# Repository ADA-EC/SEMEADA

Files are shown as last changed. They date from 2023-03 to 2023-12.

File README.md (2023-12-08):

# 🤖 SEMEADA

## O que é o projeto?
O projeto, desenvolvido pela [ADA](http://adaec.icmc.usp.br/sobre-nos/) em parceria com o [SEMEAR](https://semear.eesc.usp.br/), se trata de um robô de mesa capaz de captar comandos de fala e interpretá-los, por meio de **processamento de linguagem natural**, para realizar ações. Até o momento, o robô é capaz de obedecer aos seguintes comandos:
* Dançar
* Acordar
* Dormir
* Girar
* Levantar os braços
* Contar uma piada
* Falar sobre seu atual estado emocional
* Se apresentar
* Falar sobre a ADA
* Falar sobre o SEMEAR
* Tocar uma música
* Soletrar uma palavra
* Falar sobre o projeto

Além disso, o robô, através de máquinas de estado, possui a habilida de **simular sentimentos**, tendo assim um **"estado de espírito"**.

A seguir descrevemos mais detalhadamente o funcionamento do projeto.

## Funcionamento
Quando o robô é inicializado, o mesmo fica em estado de espera, aguardando o acionamento. Quando recebe a mensagem "Ouvir", inicia a captação de áudio (posteriormente será utilizado um botão para iniciar a captação). O áudio é armazenado em uma faixa de som (audio.wav) posteriormente enviada para `processamento_voz.py`, que utiliza a biblioteca `speech_recognition` para transformar o áudio captado em texto. O texto então é submetido 

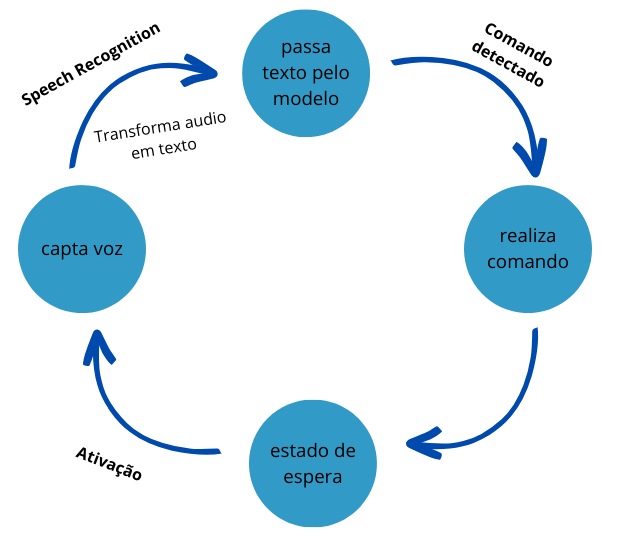
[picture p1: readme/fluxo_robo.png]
Fluxo


## Executando o projeto
### Treinando o modelo
Para treinar o modelo utilizar as instruções contidas [nesse guia](https://github.com/ADA-EC/SEMEADA/tree/main/Treinamento_PLN)

### Rodando o código
Para rodar o projeto, executar o comando: <br>
`python Esqueleto/main.py`

## Estrutura de pastas do projeto
- 📁 Codigo ➡️ contém arquivos de estudo do início do projeto
- 📁 Esqueleto ➡️ contém todo o código do robô
  - 🐍`comandos.py` ➡️ mapemaneto dos comandos em números, chamado pelo PLN
  - 🐍`commSerial.py` ➡️ faz a comunicação do código python com o Arduino, chamada pela máquina de estados
  - 🐍`main.py` ➡️ coordena todas as funções do robô
    - inicializa o robô
    - chama o processamento de áudio
    - recebe o texto de volta
    - envia o texto para o processamento
    - recebe o número do comando
    - envia para a máquina de estados   
  - 🐍`olhos.py` ➡️ mapeamento dos olhos para cada estado de humor
  - 🐍`PLN.py` ➡️ recebe o texto da *main*, faz o pré processamento do texto, submete ao modelo, retorna o valor do comando para a *main*
  - 🐍`processamento_voz.py` ➡️ chamada pela *main*, capta o áudio, transforma em texto e retorna para a *main*
  - 🐍`rostos.py` ➡️ faz a conexão com o arduino (não sei se está sendo utilizada, verificar remoção)
  - 🐍`sintese_voz.py` ➡️ usado para repetir o comando de voz de volta (verificar remoção)
  - 🐍`state_machine.py` ➡️ controla o estado de humor do robô, gerencia execução dos comandos (recebe da *main* o comando e envia para *commSerial*)
- 📁 Falhas_treinamento_PLN ➡️ contém o histórico de tentativas de treinamento do modelo
- 📁 Gravar ➡️ armazena o arquivo de áudio captado
- 📁 Maquina_Estados ➡️ contém as imagens das máquinas de estados desenvolvidas no JFLAP
- 📁 Olhos ➡️ contém os arquivos com as imagens usada para teste das telas LCD
- 📁 PCB ➡️ contém o projeto das placas do robô
- 📁 Testes Arduino ➡️ contém os arquivos comunicação com os componentes físicos do robô
- 📁 Treinamento_PLN ➡️ contém os arquivos de treinamento do modelo de processamento de linguagem natural

## O hardware

## Tecnologias Usadas

### Bibliotecas utilizadas
A seguir uma lista das bibliotecas utilizadas e como fazer sua instalação, além de dicas para contornar possíveis erros durante a instalação. (Todas as instalações foram feitas utilizando o pip, não usar o WSL)
- Pandas <br>
  `pip install pandas`
- SpaCy <br>
  `pip install spacy`
- Seaborn <br>
  `pip install seaborn`
- SpaCy Language Detector <br>
  `pip install spacy-langdetect`
- SpaCy pt_core_news_sm <br>
  `python -m spacy download pt_core_news_sm`
- gTTS <br>
  `pip install gTTS`
- SpeechRecognition [Caso não dê certo, tente rodar “pip3 install SpeechRecognition”] <br>
  `pip install SpeechRecognition`
- PlaySound [Caso não dê certo, tente dar um downgrade para a versão 1.2.2 (pip install playsound==1.2.2)] <br>
  `pip install playsound==1.2.2`
- PyDub <br>
  `pip install pydub`
- SoundDevice <br>
  `pip install sounddevice`
- SoundFile <br>
  `pip install SoundFile`
- Pyserial <br>
  `pip install pyserial`
- PyAudio <br>
  `pip install pyaudio`

### Máquina de Estados
Para realizar o projeto, fizemos algumas máquinas de estados modificadas que indicam o estado do robô após realizar os comandos.
Um exemplo disso é a maquina de estado desenvolvida para vários comandos diversos, mostrada abaixo. Nela, após realizar um comando como dançar, ele fica automaticamente no estado de "feliz".

Máquina de Estados - Diversos

Além disso, nota-se na imagem que alguns comandos não serão obedecidos se o robô estiver em determinado estado emocional, como o comando "dançar" também, que só pode ser realizado quando este está "feliz", "neutro" ou "triste".

Alguns comentários foram adicionados aos desenhos, para facilitar compreensão e auxiliar no entendimento na hora de construir o código em Python. Um exemplo de comentário pode ser visto na imagem abaixo, referente à máquina de estados "Tocar música".

Máquina de Estados - Tocar Música

## Membros
- [Érika Hortência](https://github.com/erika-hortencia)
- [Gabriela Barion Vidal](https://github.com/GabrielaVidal7)
- [Rodrigo Bragato Piva](https://github.com/Rodrigo-P)
- Marcos Almeida

## Agradecimentos
- [Victor Amaral](https://github.com/felfipe)
- [Breno Seixas]([https://github.com/TsuyoshiSonobe](https://github.com/TheGuardianB))
- [Tsuyoshi Sonobe](https://github.com/TsuyoshiSonobe)
- [Pedro Torrente](https://github.com/pdrtorrente)
- Manuella Porto

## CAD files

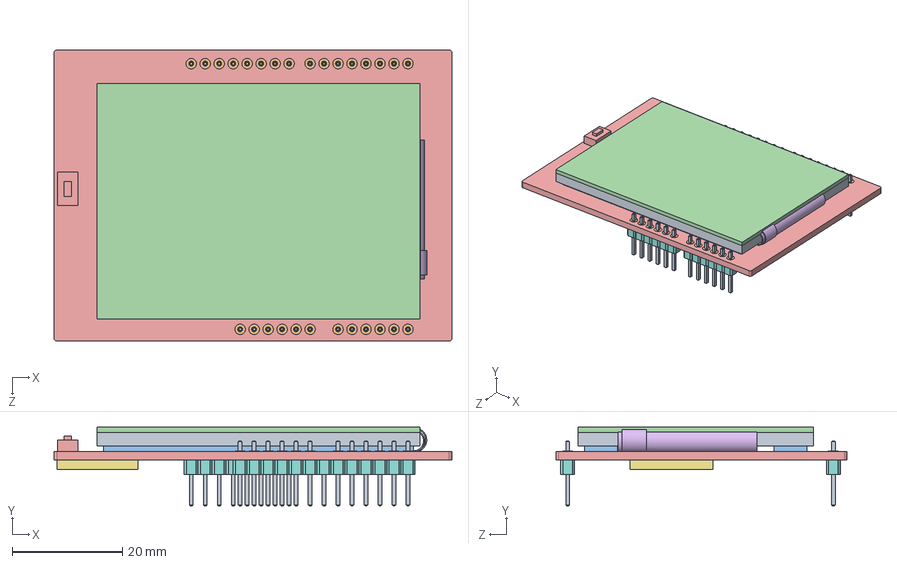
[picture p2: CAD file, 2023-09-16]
PCB/Componentes/2.4_INCH_TFT_DISPLAY_SHIELD_WITH_HEADER (1).STEP
72.3 x 14.3 x 52.9 mm
2.4INCH_TFT_DISPLAY_SHIELD_FOR_ARDUINO
PIN_HEADER_MALE_2.54MM_PITCH_6 WAY x 2
PIN_HEADER_MALE_2.54MM_PITCH_8 WAY x 2

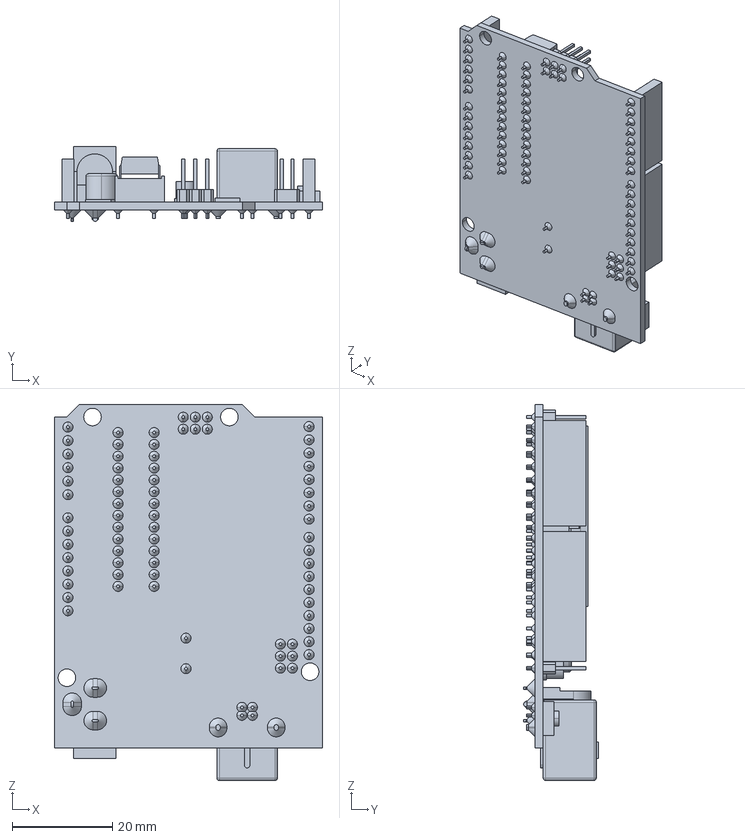
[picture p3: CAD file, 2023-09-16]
PCB/Componentes/arduino/Arduino-UNO.stp
53.5 x 14.9 x 75.0 mm

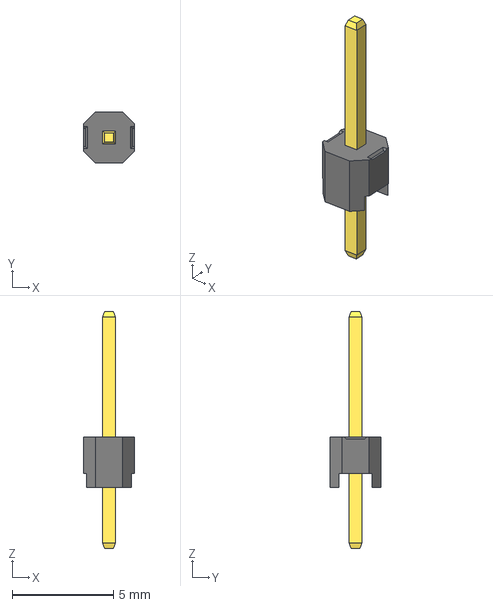
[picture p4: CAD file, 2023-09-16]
PCB/Componentes/Pin connector/PLS-1_(DS1021_CONNFLY).stp
2.54 x 2.54 x 11.7 mm

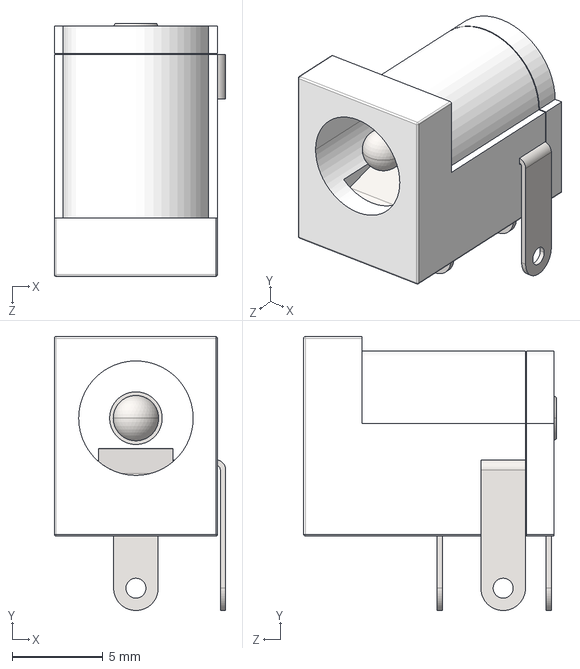
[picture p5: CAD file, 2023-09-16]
PCB/Componentes/JACK P4 PCI 2,5mm.STEP
9.45 x 15.1 x 13.9 mm

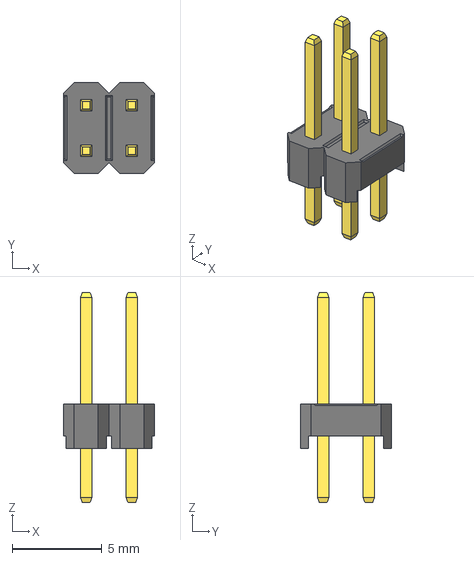
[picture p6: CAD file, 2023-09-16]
PCB/Componentes/Pin connector/PLD-4_(DS1021_CONNFLY).stp
5.08 x 5.08 x 11.7 mm

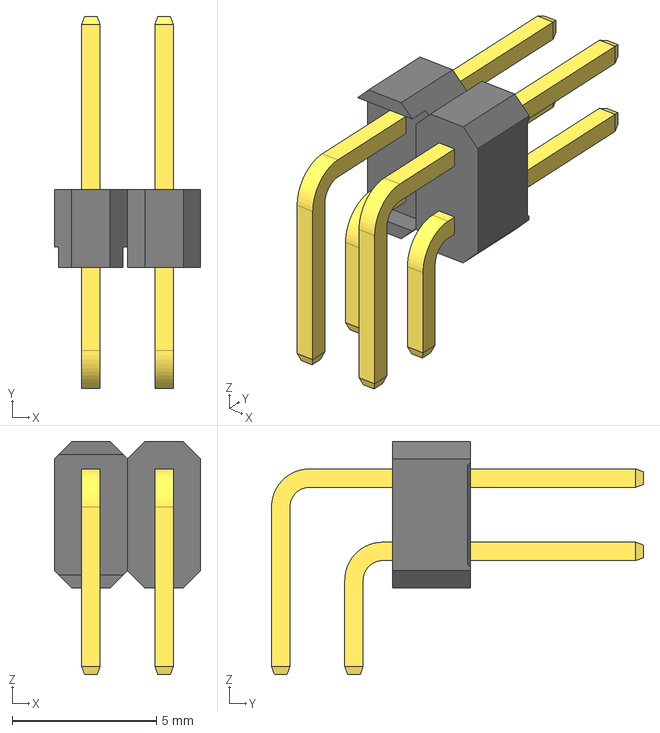
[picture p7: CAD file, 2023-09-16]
PCB/Componentes/Pin connector/PLD-4RD_(DS1022_CONNFLY).stp
5.08 x 12.9 x 8.08 mm

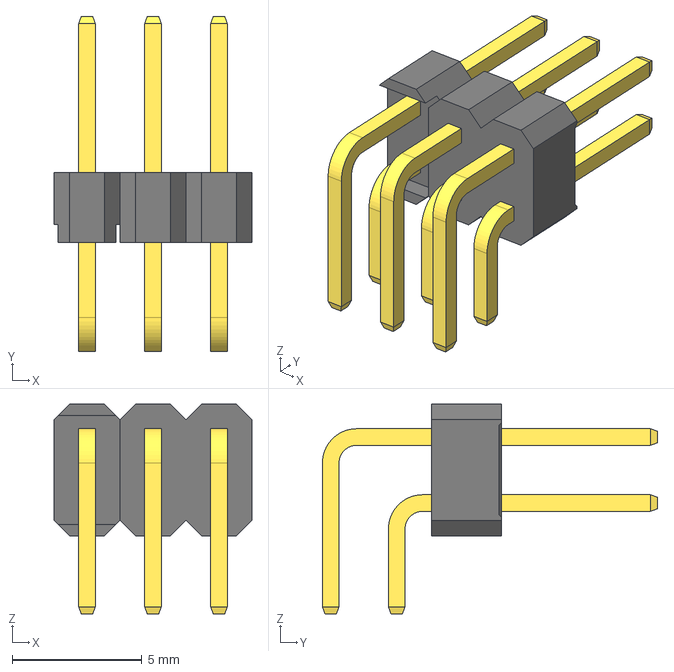
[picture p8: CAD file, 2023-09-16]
PCB/Componentes/Pin connector/PLD-6RD_(DS1022_CONNFLY).stp
7.62 x 12.9 x 8.08 mm

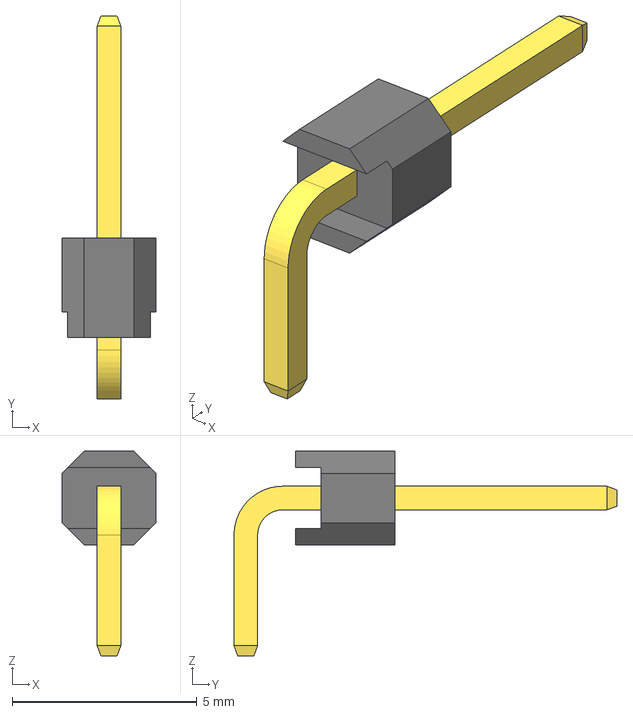
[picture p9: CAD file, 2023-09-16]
PCB/Componentes/Pin connector/PLS-1RD_(DS1022_CONNFLY).stp
2.54 x 10.4 x 5.54 mm

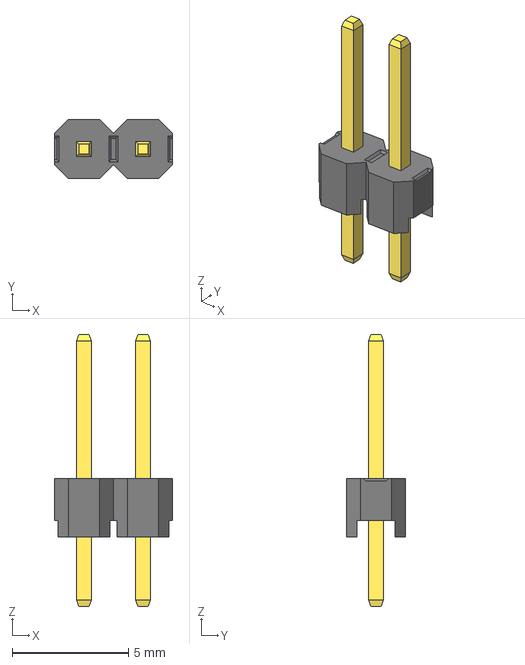
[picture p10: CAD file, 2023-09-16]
PCB/Componentes/Pin connector/PLS-2_(DS1021_CONNFLY).stp
5.08 x 2.54 x 11.7 mm

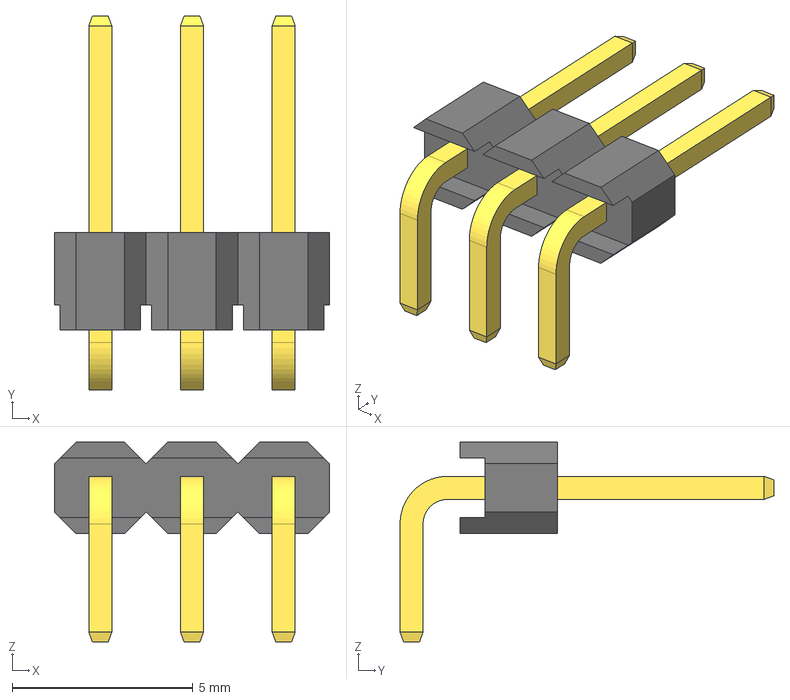
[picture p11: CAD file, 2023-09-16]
PCB/Componentes/Pin connector/PLS-3RD_(DS1022_CONNFLY).stp
7.62 x 10.4 x 5.54 mm

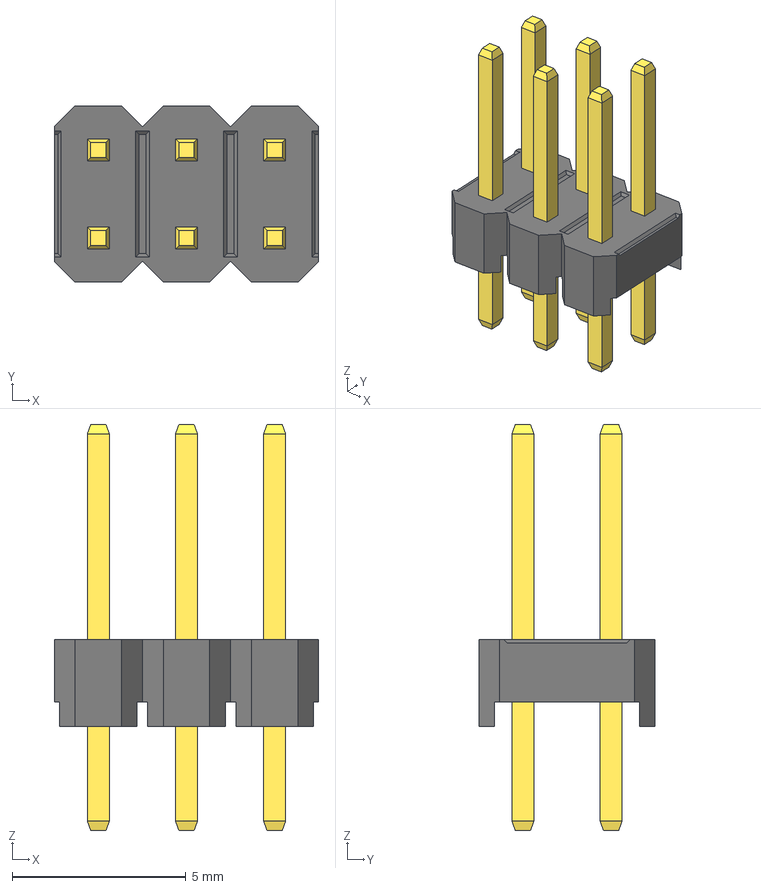
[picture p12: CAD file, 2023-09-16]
PCB/Componentes/Pin connector/PLD-6_(DS1021_CONNFLY).stp
7.62 x 5.08 x 11.7 mm

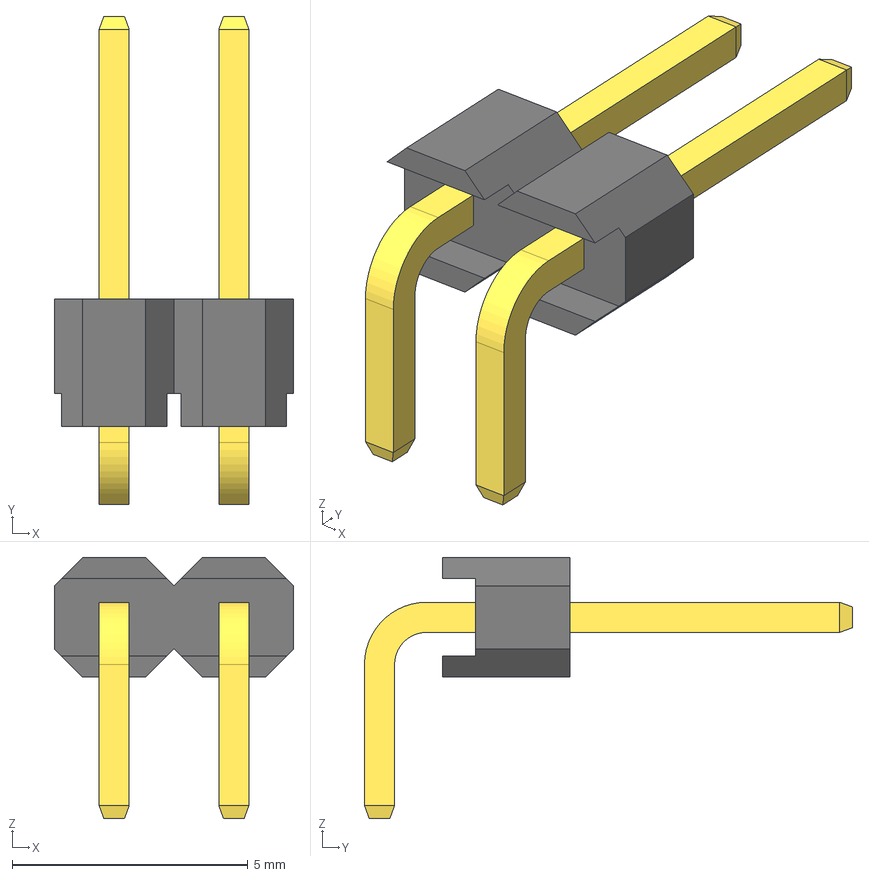
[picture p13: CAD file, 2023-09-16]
PCB/Componentes/Pin connector/PLS-2RD_(DS1022_CONNFLY).stp
5.08 x 10.4 x 5.54 mm

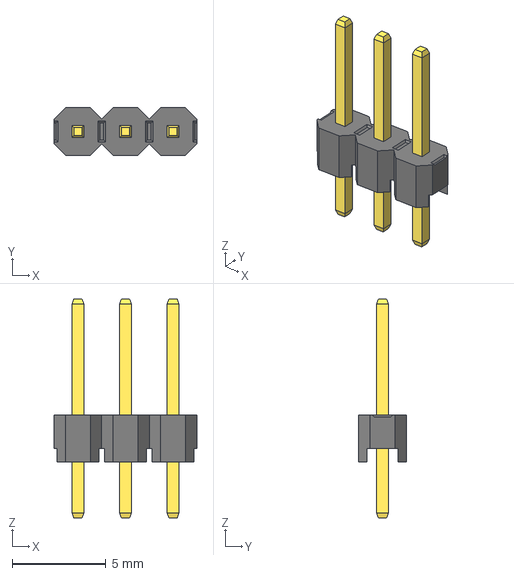
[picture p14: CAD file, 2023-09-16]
PCB/Componentes/Pin connector/PLS-3_(DS1021_CONNFLY).stp
7.62 x 2.54 x 11.7 mm

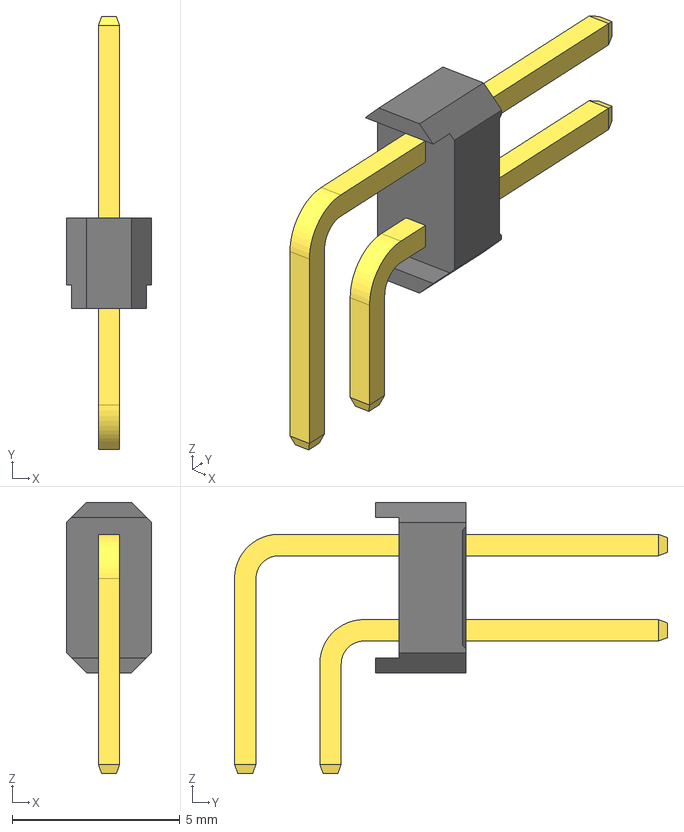
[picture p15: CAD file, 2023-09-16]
PCB/Componentes/Pin connector/PLD-2RD_(DS1022_CONNFLY).stp
2.54 x 12.9 x 8.08 mm

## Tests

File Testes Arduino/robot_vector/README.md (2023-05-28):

# Robot Eyes

Código que lê o bitmap dos olhos com diferentes emoções e mostra na tela. Resolvemos utilizar o bitmap ao invés de carregar uma imagem dos olhos na tela porque estavamos tendo problemas com o acesso da tela ao cartão microSD que ele possui.

O bitmap dos olhos está localizado no arquivo 'eyes.h'.

As animações dos olhos existentes são:
- Olho aberto
- Olho fechado
- Bravo
- Triste
- Feliz

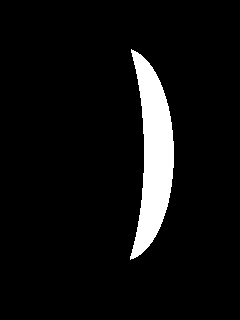
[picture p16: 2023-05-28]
Testes Arduino/TesteComunicacaoTelaSimples/feliz.bmp

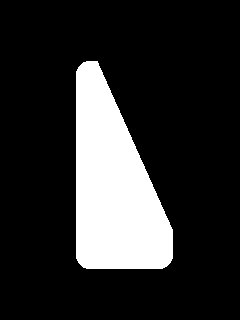
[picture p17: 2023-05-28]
Testes Arduino/TesteComunicacaoTela/triste_esq.bmp

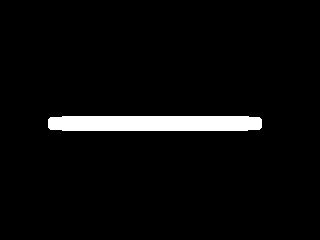
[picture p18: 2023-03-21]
Testes Arduino/robot_vector/pisca.bmp

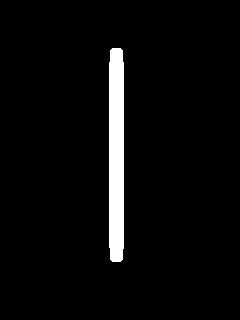
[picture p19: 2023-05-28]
Testes Arduino/TesteComunicacaoTelaSimples/pisca.bmp

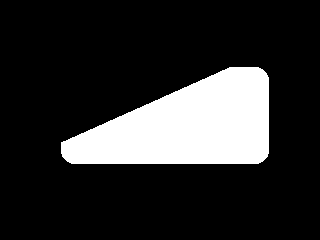
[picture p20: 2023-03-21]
Testes Arduino/robot_vector/triste_esq.bmp

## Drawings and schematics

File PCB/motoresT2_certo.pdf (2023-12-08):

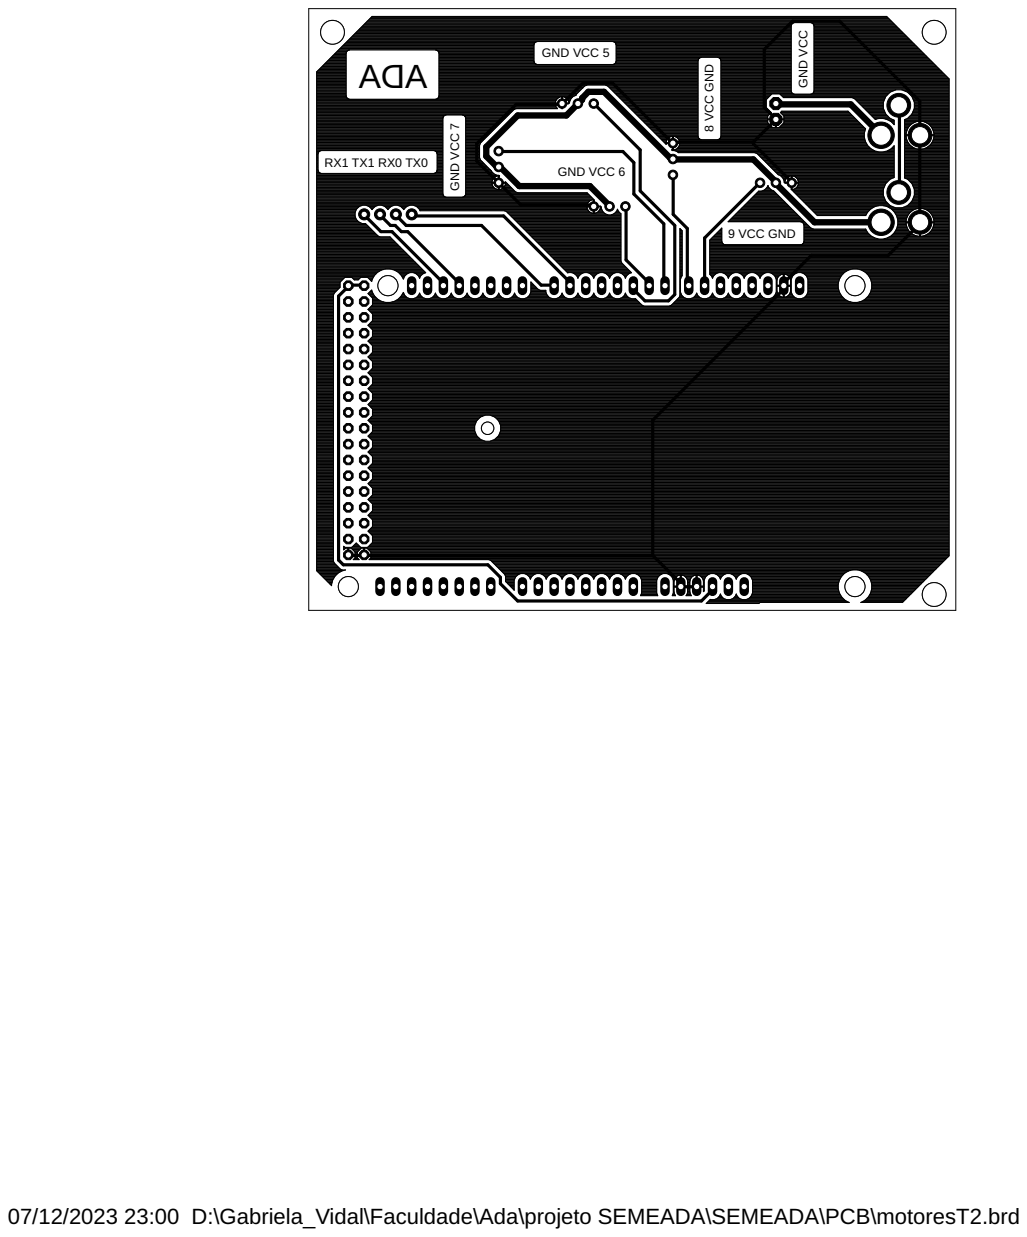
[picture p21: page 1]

07/12/2023 23:00 D:\Gabriela_Vidal\Faculdade\Ada\projeto SEMEADA\SEMEADA\PCB\motoresT2.brd

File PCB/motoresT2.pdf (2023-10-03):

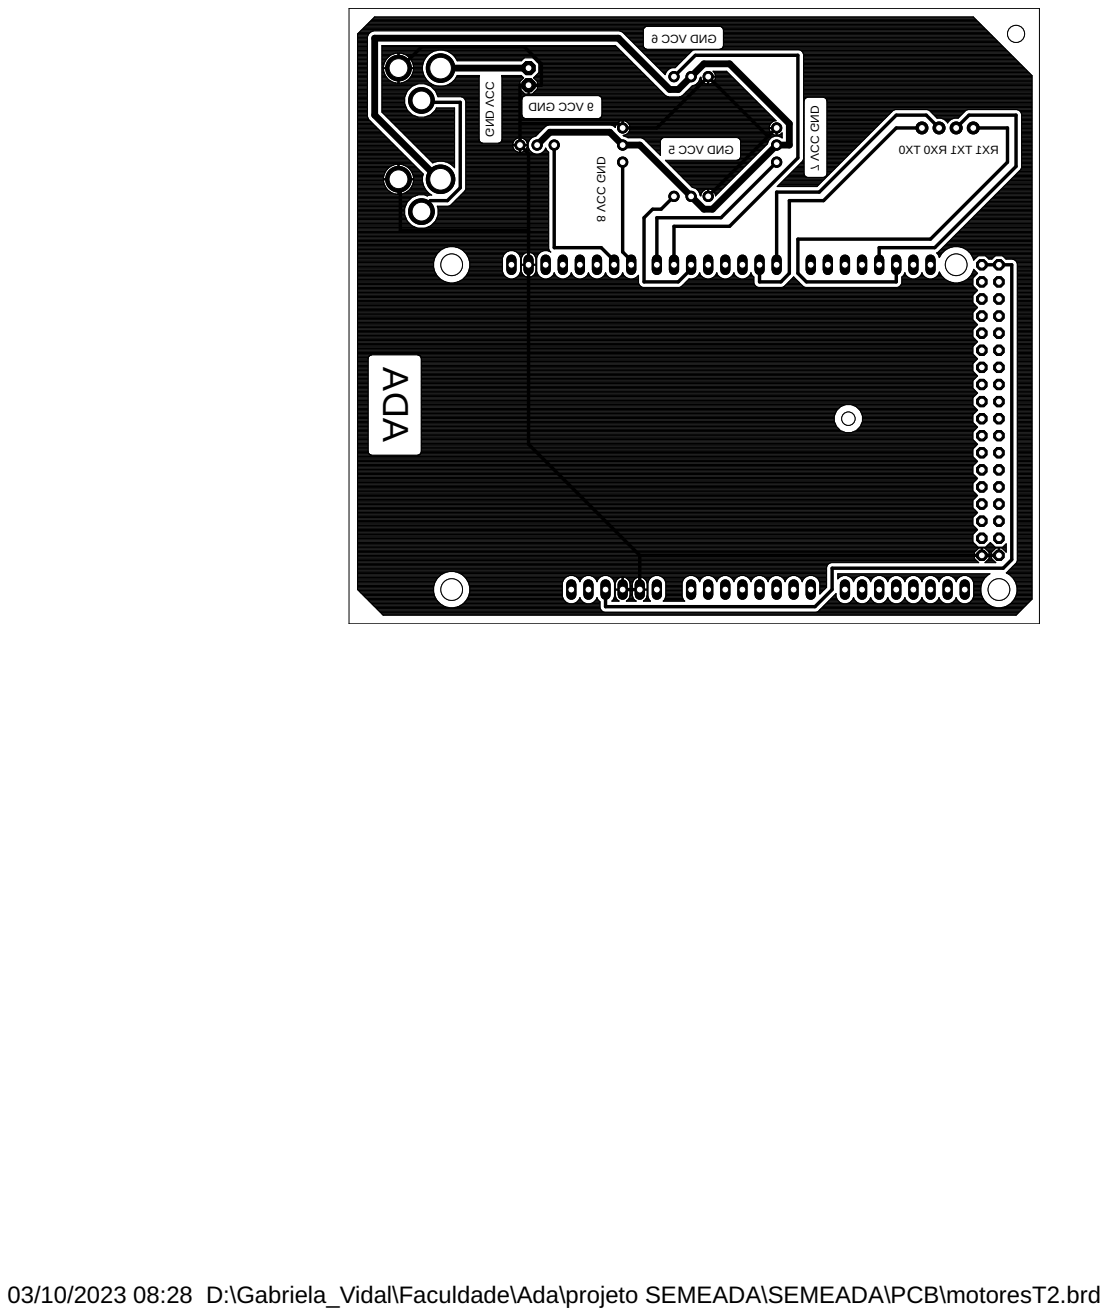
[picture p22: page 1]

03/10/2023 08:28 D:\Gabriela_Vidal\Faculdade\Ada\projeto SEMEADA\SEMEADA\PCB\motoresT2.brd

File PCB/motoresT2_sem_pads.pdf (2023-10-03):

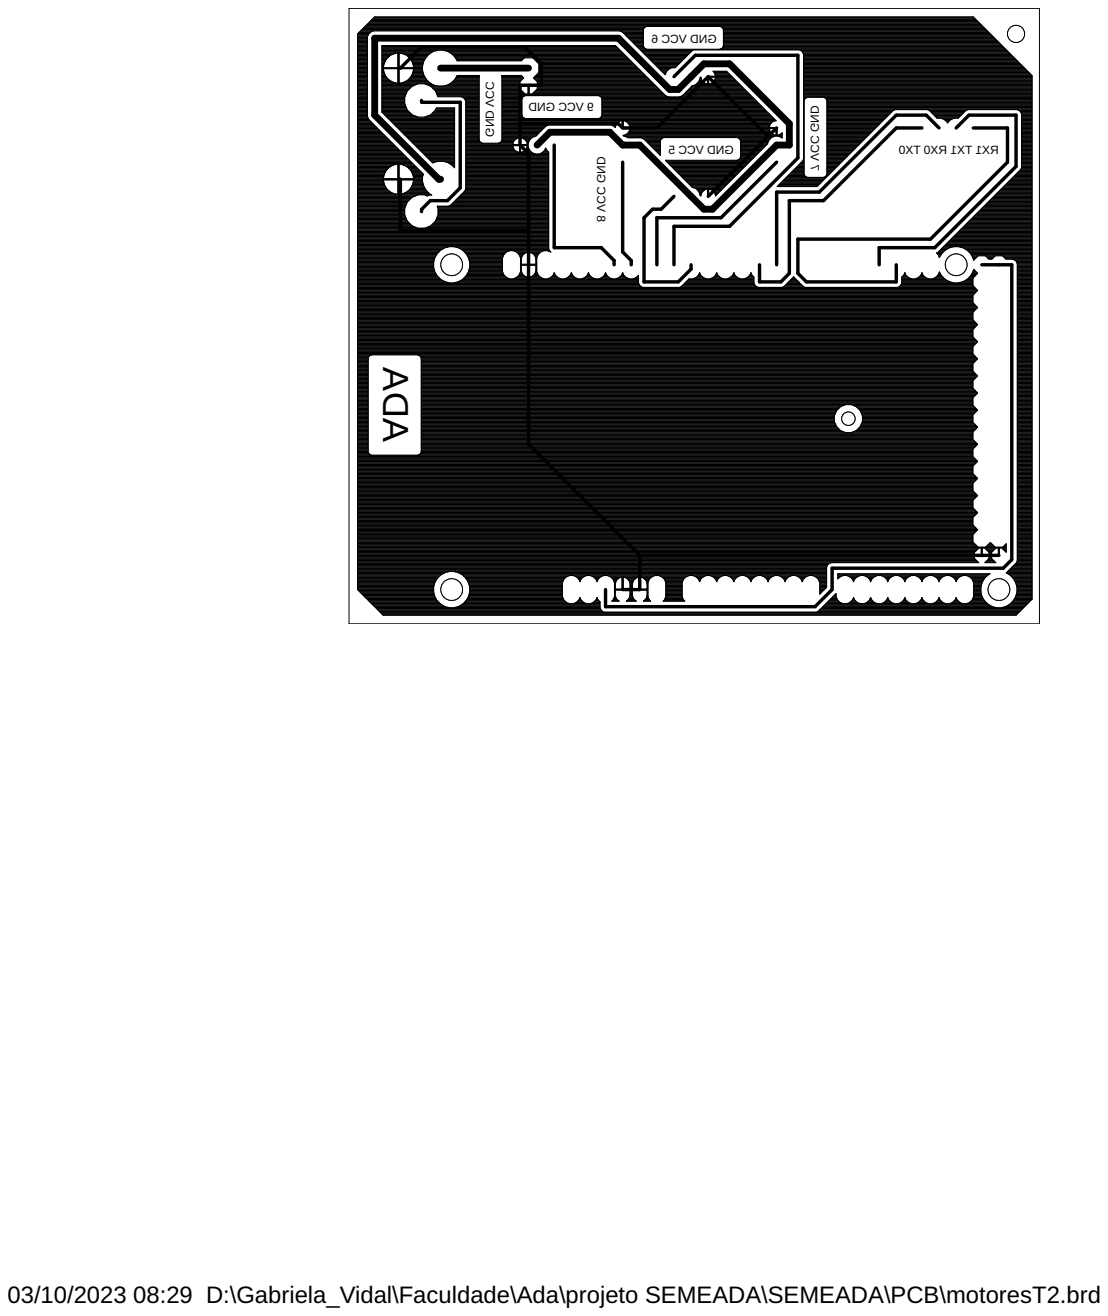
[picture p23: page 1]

03/10/2023 08:29 D:\Gabriela_Vidal\Faculdade\Ada\projeto SEMEADA\SEMEADA\PCB\motoresT2.brd

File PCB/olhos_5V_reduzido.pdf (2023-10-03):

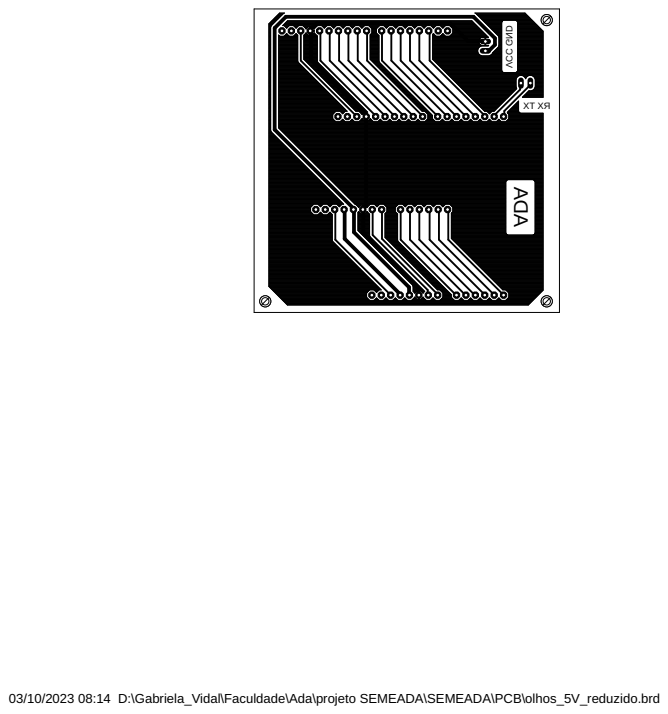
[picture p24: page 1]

03/10/2023 08:14 D:\Gabriela_Vidal\Faculdade\Ada\projeto SEMEADA\SEMEADA\PCB\olhos_5V_reduzido.brd

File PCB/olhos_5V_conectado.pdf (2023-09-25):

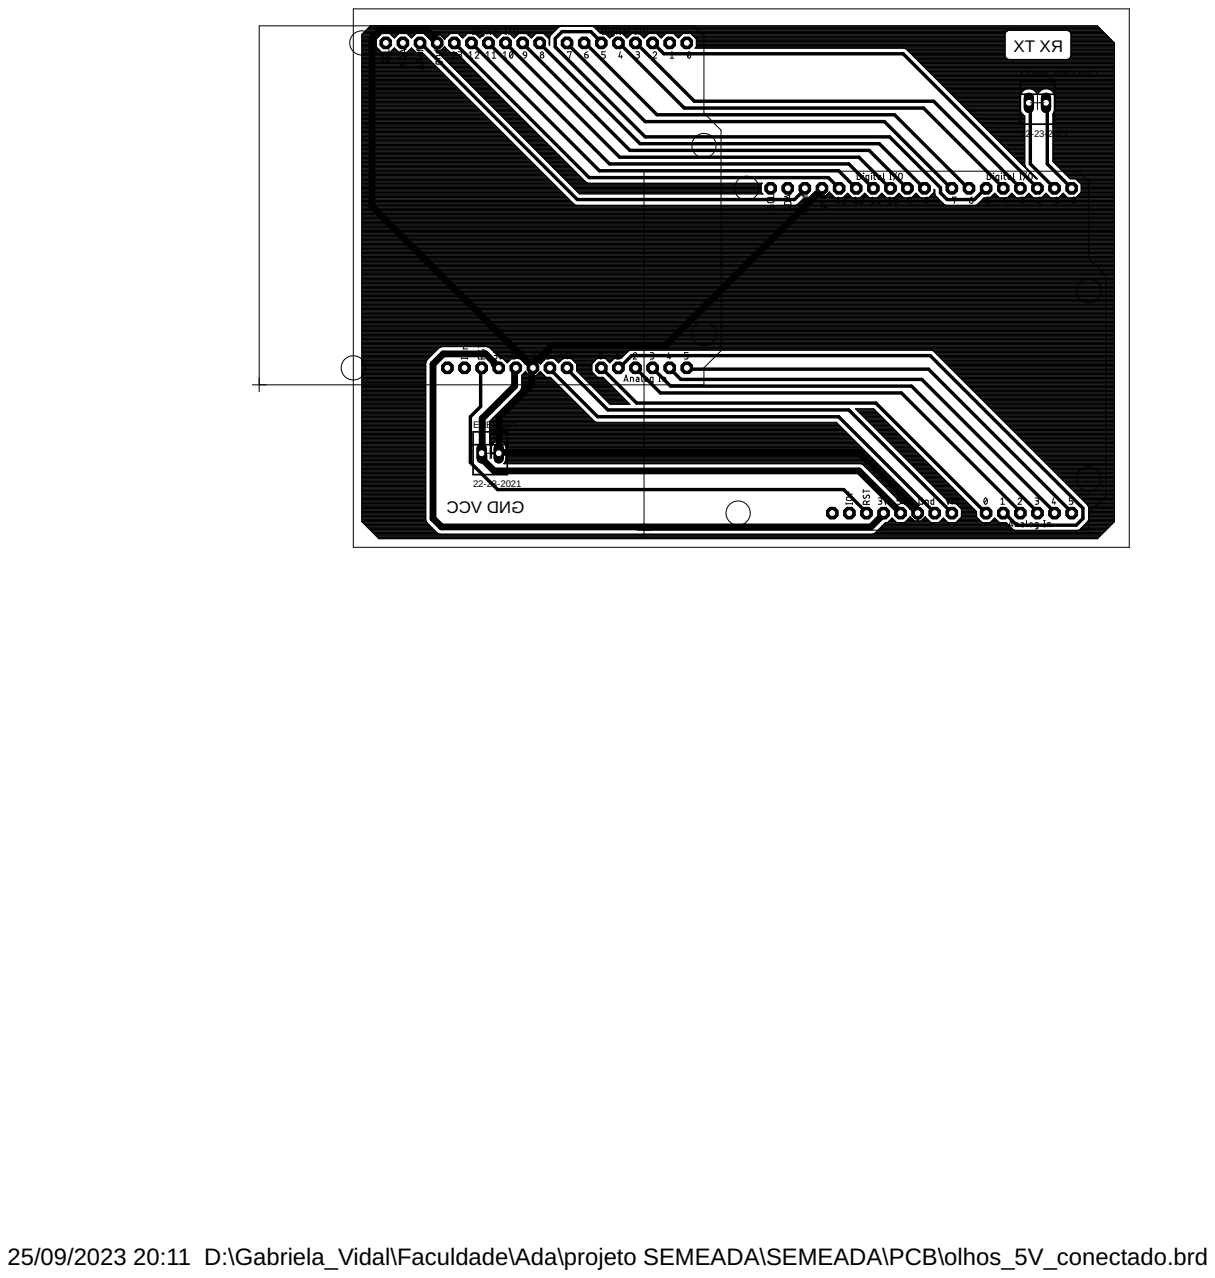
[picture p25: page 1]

25/09/2023 20:11 D:\Gabriela_Vidal\Faculdade\Ada\projeto SEMEADA\SEMEADA\PCB\olhos_5V_conectado.brd

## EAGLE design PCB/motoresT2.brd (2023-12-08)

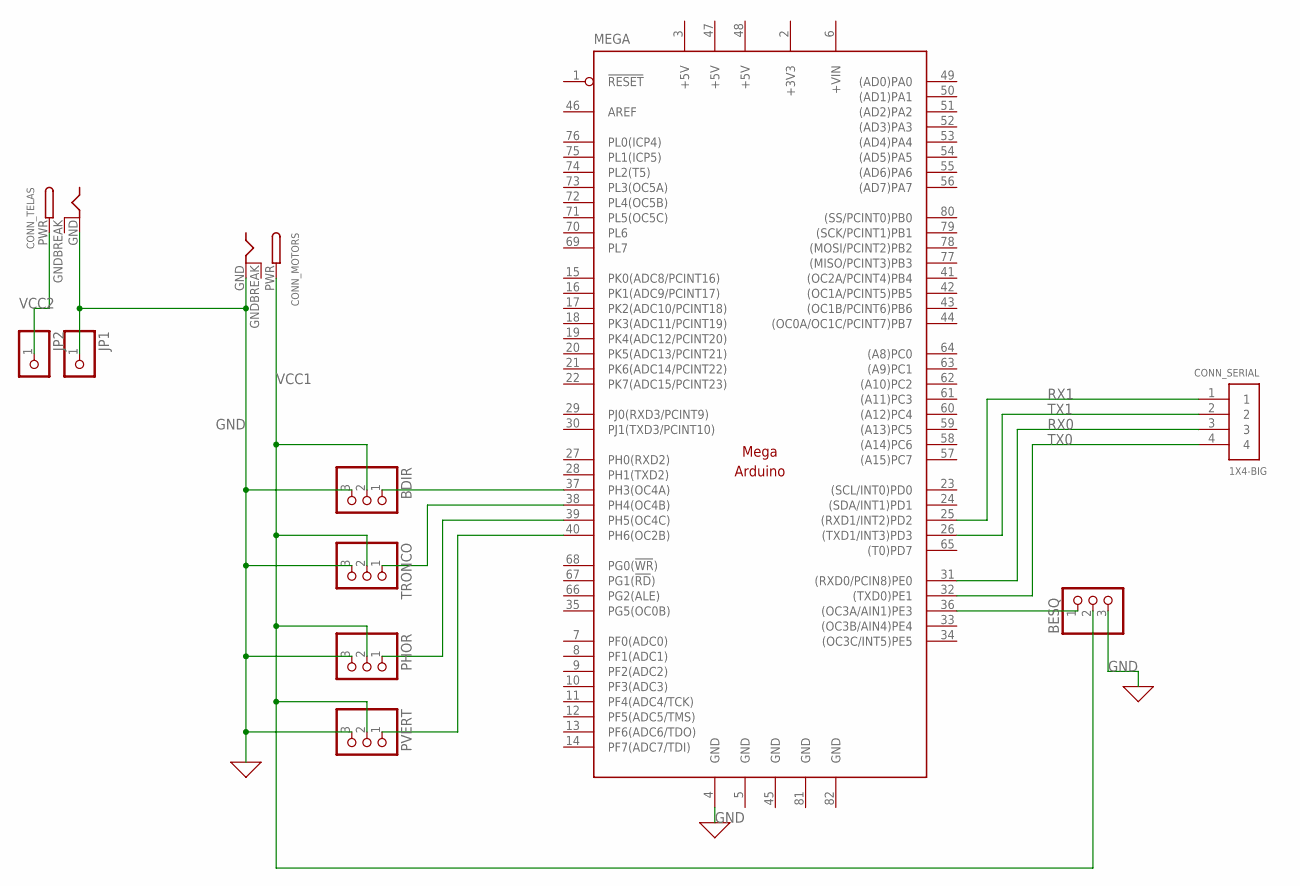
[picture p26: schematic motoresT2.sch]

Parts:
BDIR: PINHD-1X3; 1X03
BESQ: PINHD-1X3; 1X03
CONN_MOTORS: DCBARRELPTH; DCJACK_2MM_PTH
CONN_SERIAL: 1X4-BIG; 1X04-BIG
CONN_TELAS: DCBARRELPTH; DCJACK_2MM_PTH
JP1, JP2: PINHD-1X1; 1X01
MEGA: MEGAARDUINO_11; MEGA_ARDUINO_1
PHOR: PINHD-1X3; 1X03
PVERT: PINHD-1X3; 1X03
TRONCO: PINHD-1X3; 1X03

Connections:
+3V3: MEGA.2 (+3V3)
+5V: MEGA.3 (+5V), MEGA.47 (+5V), MEGA.48 (+5V)
+VIN: MEGA.6 (+VIN)
GND: BDIR.3, BESQ.3, CONN_MOTORS.GND, CONN_TELAS.GND, JP1.1, MEGA.4 (GND), MEGA.5 (GND), MEGA.45 (GND), MEGA.81 (GND), MEGA.82 (GND), PHOR.3, PVERT.3, TRONCO.3
GNDBREAK: CONN_MOTORS.GNDBREAK, CONN_TELAS.GNDBREAK
unnamed: BDIR.1, MEGA.37 (PH3(OC4A))
unnamed: MEGA.38 (PH4(OC4B)), TRONCO.1
unnamed: MEGA.39 (PH5(OC4C)), PHOR.1
unnamed: MEGA.40 (PH6(OC2B)), PVERT.1
unnamed: BESQ.1, MEGA.36 ((OC3A/AIN1)PE3)
RX0: CONN_SERIAL.3, MEGA.31 ((RXD0/PCIN8)PE0)
RX1: CONN_SERIAL.1, MEGA.25 ((RXD1/INT2)PD2)
TX0: CONN_SERIAL.4, MEGA.32 ((TXD0)PE1)
TX1: CONN_SERIAL.2, MEGA.26 ((TXD1/INT3)PD3)
VCC1: BDIR.2, BESQ.2, CONN_MOTORS.PWR, PHOR.2, PVERT.2, TRONCO.2
VCC2: CONN_TELAS.PWR, JP2.1

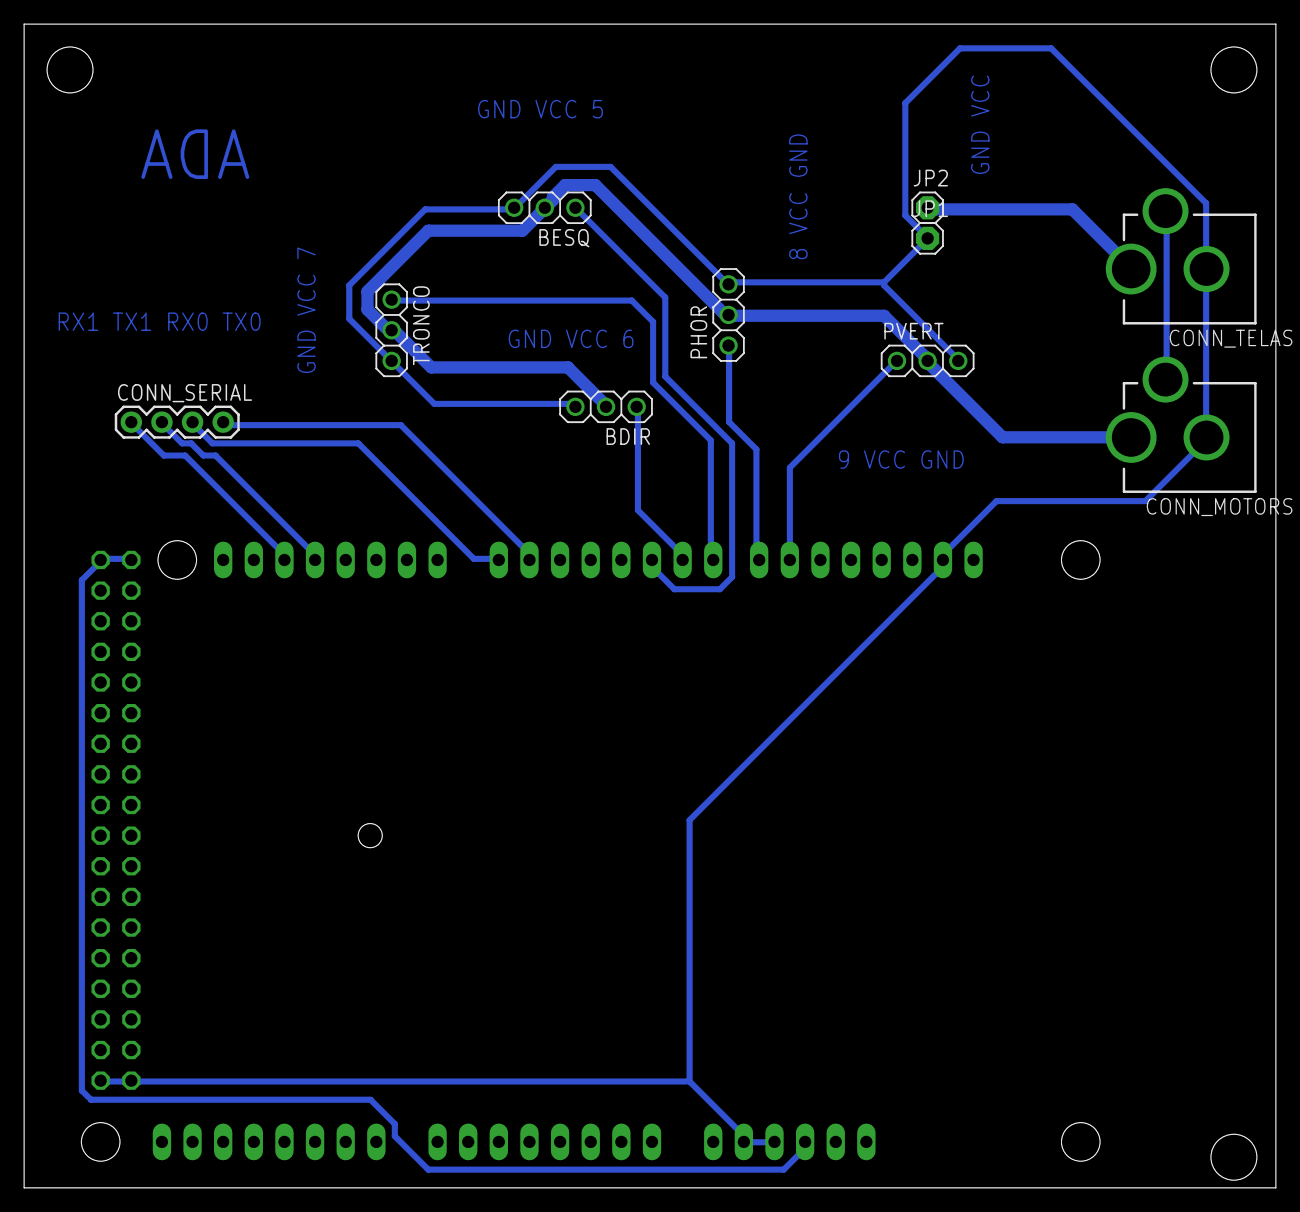
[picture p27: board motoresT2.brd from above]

Board: 2 copper layers, 103.8 x 96.5 mm, 11 parts (1 on the bottom side), 14 nets.

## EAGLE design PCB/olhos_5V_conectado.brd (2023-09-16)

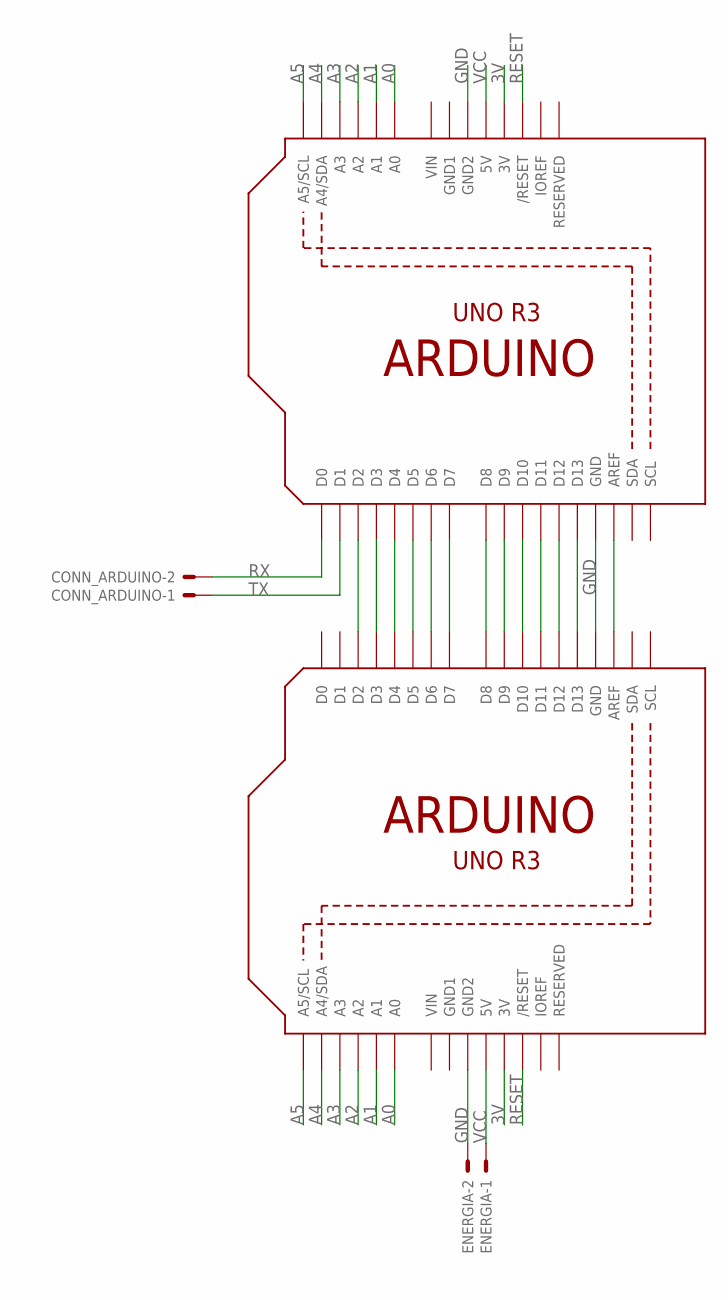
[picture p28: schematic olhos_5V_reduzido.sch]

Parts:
CONN_ARDUINO: 22-23-2021
ENERGIA: 22-23-2021
TELA_LCD: ARDUINOR3-BPLACE
U2: ARDUINOR3-BPLACE

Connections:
3V: TELA_LCD.3V, U2.3V
A0: TELA_LCD.A0, U2.A0
A1: TELA_LCD.A1, U2.A1
A2: TELA_LCD.A2, U2.A2
A3: TELA_LCD.A3, U2.A3
A4: TELA_LCD.A4 (A4/SDA), U2.A4 (A4/SDA)
A5: TELA_LCD.A5 (A5/SCL), U2.A5 (A5/SCL)
GND: ENERGIA.2, TELA_LCD.GND, TELA_LCD.GND2, U2.GND, U2.GND2
GND1: TELA_LCD.GND1, U2.GND1
unnamed: TELA_LCD.D2, U2.D2
unnamed: TELA_LCD.D3, U2.D3
unnamed: TELA_LCD.D4, U2.D4
unnamed: TELA_LCD.D5, U2.D5
unnamed: TELA_LCD.D6, U2.D6
unnamed: TELA_LCD.D7, U2.D7
unnamed: TELA_LCD.D8, U2.D8
unnamed: TELA_LCD.D9, U2.D9
unnamed: TELA_LCD.D10, U2.D10
unnamed: TELA_LCD.D11, U2.D11
unnamed: TELA_LCD.D12, U2.D12
unnamed: TELA_LCD.D13, U2.D13
unnamed: TELA_LCD.AREF, U2.AREF
RESET: TELA_LCD.RESET (/RESET), U2.RESET (/RESET)
RX: CONN_ARDUINO.2, U2.D0
TX: CONN_ARDUINO.1, U2.D1
VCC: ENERGIA.1, TELA_LCD.5V, U2.5V
VIN: TELA_LCD.VIN, U2.VIN

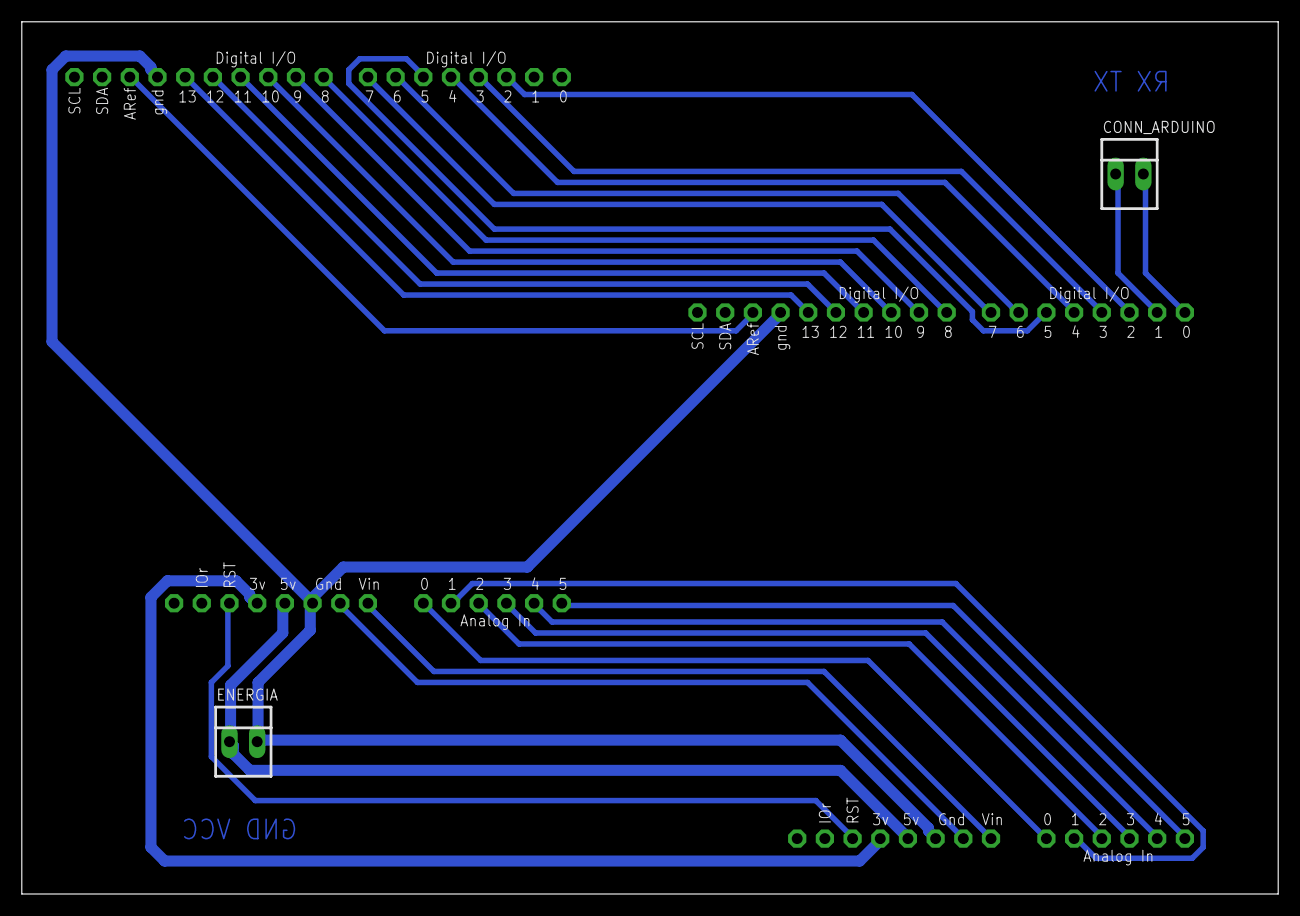
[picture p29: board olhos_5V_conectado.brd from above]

Board: 2 copper layers, 115.2 x 80.0 mm, 4 parts (0 on the bottom side), 27 nets.

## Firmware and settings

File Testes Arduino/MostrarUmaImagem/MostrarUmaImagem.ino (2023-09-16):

// MCUFRIEND UNO shields have microSD on pins 10, 11, 12, 13
// The official <SD.h> library only works on the hardware SPI pins
// e.g. 11, 12, 13 on a Uno  (or STM32 Nucleo)
//
// copy all your BMP files to the root directory on the microSD with your PC
// (or another directory)
#include <MCUFRIEND_kbv.h>
#include <Adafruit_GFX.h>   // Hardware-specific library
#include <SPI.h>            // f.k. for Arduino-1.5.2
#include <SD.h>             // Use the official SD library on hardware pins

#define PALETTEDEPTH   0     // do not support Palette modes
#define SD_CS     10

MCUFRIEND_kbv tft;
int pathlen;
File root;

void setup(){
    uint16_t ID;
    Serial.begin(9600);
    Serial.print("Show BMP files on TFT with ID:0x");
    ID = tft.readID();
    Serial.println(ID, HEX);
    if (ID == 0x0D3D3) ID = 0x9481;
    tft.begin(ID);
    tft.fillScreen(0x001F);
    tft.setTextColor(0xFFFF, 0x0000);
    bool good = SD.begin(SD_CS);
    if (!good) {
        Serial.print(F("cannot start SD"));
        while (1);
    }
    uint8_t ret = showBMP("pisca.bmp", 0, 0);
}

void loop(){
}

#define BMPIMAGEOFFSET 54
#define BUFFPIXEL      20

uint16_t read16(File& f) {
    uint16_t result;         // read little-endian
    f.read((uint8_t*)&result, sizeof(result));
    return result;
}

uint32_t read32(File& f) {
    uint32_t result;
    f.read((uint8_t*)&result, sizeof(result));
    return result;
}

uint8_t showBMP(char *nm, int x, int y){
    File bmpFile;
    int bmpWidth, bmpHeight;    // W+H in pixels
    uint8_t bmpDepth;           // Bit depth (currently must be 24, 16, 8, 4, 1)
    uint32_t bmpImageoffset;    // Start of image data in file
    uint32_t rowSize;           // Not always = bmpWidth; may have padding
    uint8_t sdbuffer[3 * BUFFPIXEL];    // pixel in buffer (R+G+B per pixel)
    uint16_t lcdbuffer[(1 << PALETTEDEPTH) + BUFFPIXEL], *palette = NULL;
    uint8_t bitmask, bitshift;
    boolean flip = true;        // BMP is stored bottom-to-top
    int w, h, row, col, lcdbufsiz = (1 << PALETTEDEPTH) + BUFFPIXEL, buffidx;
    uint32_t pos;               // seek position
    boolean is565 = false;      //

    uint16_t bmpID;
    uint16_t n;                 // blocks read
    uint8_t ret;

    if ((x >= tft.width()) || (y >= tft.height()))
        return 1;               // off screen

    bmpFile = SD.open(nm);      // Parse BMP header
    bmpID = read16(bmpFile);    // BMP signature
    (void) read32(bmpFile);     // Read & ignore file size
    (void) read32(bmpFile);     // Read & ignore creator bytes
    bmpImageoffset = read32(bmpFile);       // Start of image data
    (void) read32(bmpFile);     // Read & ignore DIB header size
    bmpWidth = read32(bmpFile);
    bmpHeight = read32(bmpFile);
    n = read16(bmpFile);        // # planes -- must be '1'
    bmpDepth = read16(bmpFile); // bits per pixel
    pos = read32(bmpFile);      // format
    if (bmpID != 0x4D42) ret = 2; // bad ID
    else if (n != 1) ret = 3;   // too many planes
    else if (pos != 0 && pos != 3) ret = 4; // format: 0 = uncompressed, 3 = 565
    else if (bmpDepth < 16 && bmpDepth > PALETTEDEPTH) ret = 5; // palette 
    else {
        bool first = true;
        is565 = (pos == 3);               // ?already in 16-bit format
        // BMP rows are padded (if needed) to 4-byte boundary
        rowSize = (bmpWidth * bmpDepth / 8 + 3) & ~3;
        if (bmpHeight < 0) {              // If negative, image is in top-down order.
            bmpHeight = -bmpHeight;
            flip = false;
        }

        w = bmpWidth;
        h = bmpHeight;
        if ((x + w) >= tft.width())       // Crop area to be loaded
            w = tft.width() - x;
        if ((y + h) >= tft.height())      //
            h = tft.height() - y;

        if (bmpDepth <= PALETTEDEPTH) {   // these modes have separate palette
            //bmpFile.seek(BMPIMAGEOFFSET); //palette is always @ 54
            bmpFile.seek(bmpImageoffset - (4<<bmpDepth)); //54 for regular, diff for colorsimportant
            bitmask = 0xFF;
            if (bmpDepth < 8)
                bitmask >>= bmpDepth;
            bitshift = 8 - bmpDepth;
            n = 1 << bmpDepth;
            lcdbufsiz -= n;
            palette = lcdbuffer + lcdbufsiz;
            for (col = 0; col < n; col++) {
                pos = read32(bmpFile);    //map palette to 5-6-5
                palette[col] = ((pos & 0x0000F8) >> 3) | ((pos & 0x00FC00) >> 5) | ((pos & 0xF80000) >> 8);
            }
        }

        // Set TFT address window to clipped image bounds
        tft.setAddrWindow(x, y, x + w - 1, y + h - 1);
        for (row = 0; row < h; row++) { // For each scanline...
            // Seek to start of scan line.  It might seem labor-
            // intensive to be doing this on every line, but this
            // method covers a lot of gritty details like cropping
            // and scanline padding.  Also, the seek only takes
            // place if the file position actually needs to change
            // (avoids a lot of cluster math in SD library).
            uint8_t r, g, b, *sdptr;
            int lcdidx, lcdleft;
            if (flip)   // Bitmap is stored bottom-to-top order (normal BMP)
                pos = bmpImageoffset + (bmpHeight - 1 - row) * rowSize;
            else        // Bitmap is stored top-to-bottom
                pos = bmpImageoffset + row * rowSize;
            if (bmpFile.position() != pos) { // Need seek?
                bmpFile.seek(pos);
                buffidx = sizeof(sdbuffer); // Force buffer reload
            }

            for (col = 0; col < w; ) {  //pixels in row
                lcdleft = w - col;
                if (lcdleft > lcdbufsiz) lcdleft = lcdbufsiz;
                for (lcdidx = 0; lcdidx < lcdleft; lcdidx++) { // buffer at a time
                    uint16_t color;
                    // Time to read more pixel data?
                    if (buffidx >= sizeof(sdbuffer)) { // Indeed
                        bmpFile.read(sdbuffer, sizeof(sdbuffer));
                        buffidx = 0; // Set index to beginning
                        r = 0;
                    }
                    switch (bmpDepth) {          // Convert pixel from BMP to TFT format
                        case 24:
                            b = sdbuffer[buffidx++];
                            g = sdbuffer[buffidx++];
                            r = sdbuffer[buffidx++];
                            color = tft.color565(r, g, b);
                            break;
                        case 16:
                            b = sdbuffer[buffidx++];
                            r = sdbuffer[buffidx++];
                            if (is565)
                                color = (r << 8) | (b);
                            else
                                color = (r << 9) | ((b & 0xE0) << 1) | (b & 0x1F);
                            break;
                        case 1:
                        case 4:
                        case 8:
                            if (r == 0)
                                b = sdbuffer[buffidx++], r = 8;
                            color = palette[(b >> bitshift) & bitmask];
                            r -= bmpDepth;
                            b <<= bmpDepth;
                            break;
                    }
                    lcdbuffer[lcdidx] = color;

                }
                tft.pushColors(lcdbuffer, lcdidx, first);
                first = false;
                col += lcdidx;
            }           // end cols
        }               // end rows
        tft.setAddrWindow(0, 0, tft.width() - 1, tft.height() - 1); //restore full screen
        ret = 0;        // good render
    }
    bmpFile.close();
    return (ret);
}

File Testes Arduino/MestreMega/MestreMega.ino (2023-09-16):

#include <Servo.h>
#include <SPI.h>            // f.k. for Arduino-1.5.2
#include <SD.h>             // Use the official SD library on hardware pins

int pathlen;
File root;

Servo servos[5];  // create servo object to control a servo

// int16_t incremento[5];	//array que guarda o quanto os servos têm que se movimentar
// int16_t pos_at[7];	//array que guarda a posicao atual dos componentes do robô
int16_t msg[12];	//array que recebe todas o comando decodificado
byte buff[24];	//array que recebe a comunicação serial
int i;


void setup() {
  // Begin the Serial at 9600 Baud
  Serial.begin(9600);
  Serial1.begin(9600);
  Serial2.begin(9600);
  
  for(i = 0; i < 5; i ++){
    servos[i].attach(5+i);  //Cria objetos dos servos
  }
  for(i = 0; i < 5; i ++){
    servos[i].write(0);  //Reseta os servos para a posição inicial
  }
  
  memset(msg,0,12*sizeof(int16_t)); //set msg to 0
//   memset(pos_at,0,7*sizeof(int16_t)); //set pos to 0
}


void loop() {
  while(!Serial.available());	//Aguarda mensagem serial
  Serial.readBytes(buff, 24);	//Recebe a mensagem serial

  for(i = 0; i < 12; i++){
    msg[i] = buff[2*i] + (buff[(2*i)+1] << 8);	//Decodifica a mensagem para números
  } 

  Serial1.write(msg[10]);	//Envia mensagem para Olho_1
  Serial2.write(msg[11]);	//Envia mensagem para Olho_2
  
  for(i = 0; i < 5; i ++){
    servos[i].write(msg[2*i]);  //Movimenta servo-motores
  }
}

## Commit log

2022-05-19 Implementação dos códigos e uso das bibliotecas para comunicação com tela touch
2022-05-20 Código teste para comunicação com o arduino
2022-05-26 arrumando conexão como arduino
2022-06-28 Função de enviar mensagem para Arduino criada em Python
2022-07-18 Continuando teste do servo motor
2022-08-17 Arrumando comunicação arduino-Python
2022-09-02 Controle do Servo
2023-03-21 alterações
    [robot face.stl]
2023-05-20 Melhoras na conexão com o Arduino
2023-05-28 primeiro intensivão
    [robot face.stl]
2023-06-07 PCB dos motores em andamento
    [JACK P4 PCI 2,5mm.STEP, PLD-2RD_(DS1022_CONNFLY).stp, PLD-4RD_(DS1022_CONNFLY).stp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]
2023-06-18 1o prototipo da PCB dos motores finalizado
    [motores.brd, motoresT1.brd, motoresT1.sch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]
2023-09-13 PCB olhos pronta
    [2.4_INCH_TFT_DISPLAY_SHIELD_WITH_HEADER (1).STEP, Arduino-UNO.stp, DRILEGEND.CFG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]
2023-09-16 olho nao usado
    [olhos.brd, olhos.sch]
2023-09-25 PCB dos olhos reduzida
    [olhos_5V_reduzido.brd, olhos_5V_reduzido.sch]
2023-10-03 Arquivos de impressão da PCB arrumados
    [motoresT2.brd]
2023-10-03 Mais formatos de impressão das PCBs
2023-10-19 Added catch and warning in case there's no command for the arduino
2023-10-19 Adicionando imagem para readme
2023-10-19 Redimensionando imagem para readme
2023-10-20 Update README.md
    Adicionando:
    Descrição do projeto
    Funcionamento
    Como rodar o projeto
    Bibliotecas utilizadas
    Estrutura de pastas
2023-10-20 Update README.md
    Adicionando link para instruções de treinamento do modelo
2023-11-16 Simplificando configuração de motores e olhos
2023-11-16 Melhorando funcionamento de piadas e soletrar
2023-11-16 Unificação de Enums e dicionários em arquivo único
2023-12-08 PCD motores arrumada
    [motoresT2.brd, motoresT2.sch]
2023-12-12 PCBs atualizadas
